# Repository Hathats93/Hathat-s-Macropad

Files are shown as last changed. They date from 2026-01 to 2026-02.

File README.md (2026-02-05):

# Hathats' Macropad

# Complete case with switches and keycaps installed
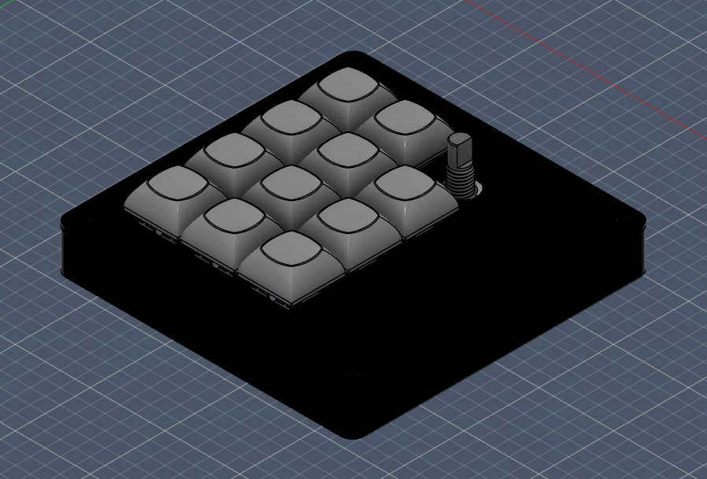
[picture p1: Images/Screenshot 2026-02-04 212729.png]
image alt


# Bare case (top and bottom)
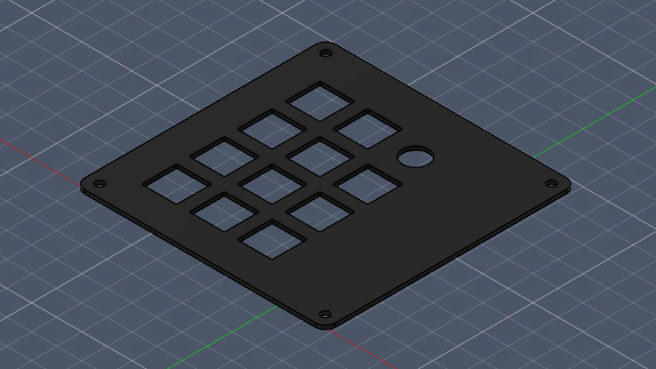
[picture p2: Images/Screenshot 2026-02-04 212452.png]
image alt


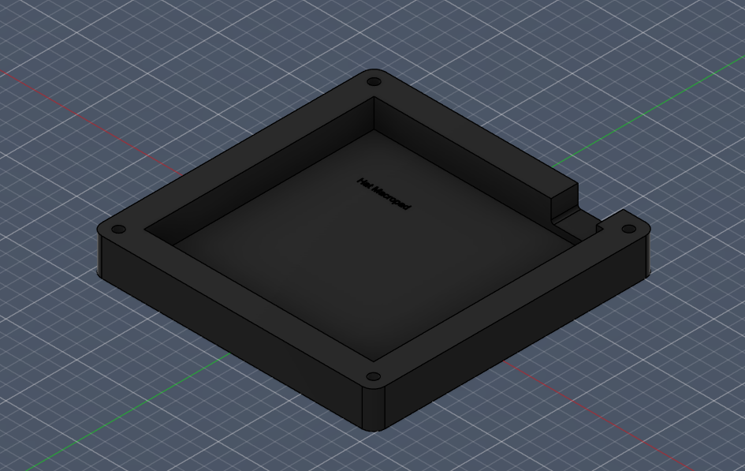
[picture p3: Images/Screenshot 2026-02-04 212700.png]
image alt


# PCB schematic
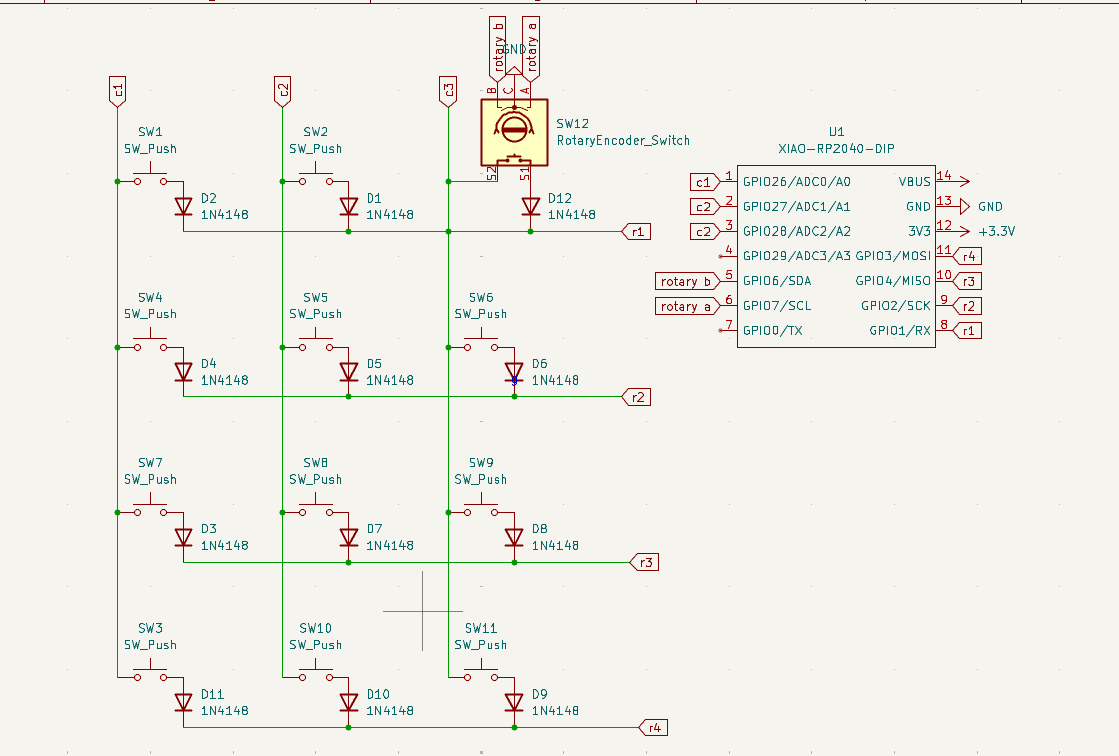
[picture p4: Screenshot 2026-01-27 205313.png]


# PCB layout
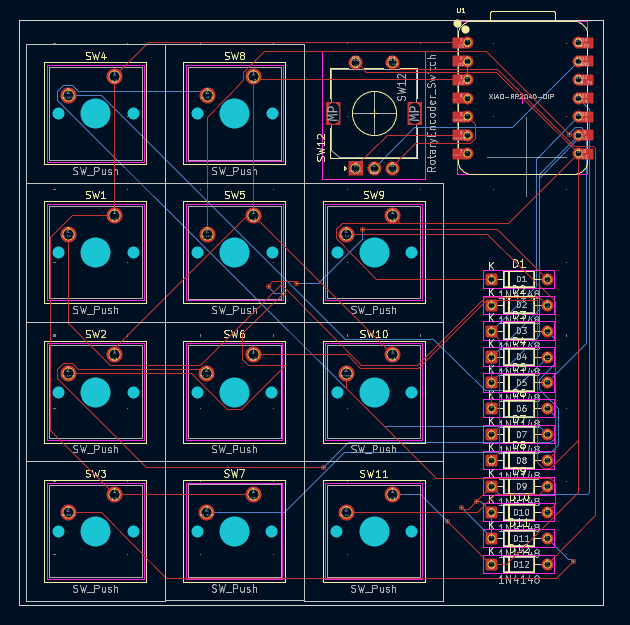
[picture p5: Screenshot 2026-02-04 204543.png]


##  Bill of Materials/BOM
List of all parts used in my hackpad:

| Part | Quantity | Description | 
|---|---|---|
| Mechanical Key Switches | 11 | MX-style switches |
| DSA Keycaps | 11 | Compatible with MX switches | 
| Seeed XIAO RP2040 | 1 | Microcontroller | 
| EC11 Rotary Encoder | 1 | Volume control | 
| PCB | 1 | Double-sided | 
| Case | 1 | 3D printed |

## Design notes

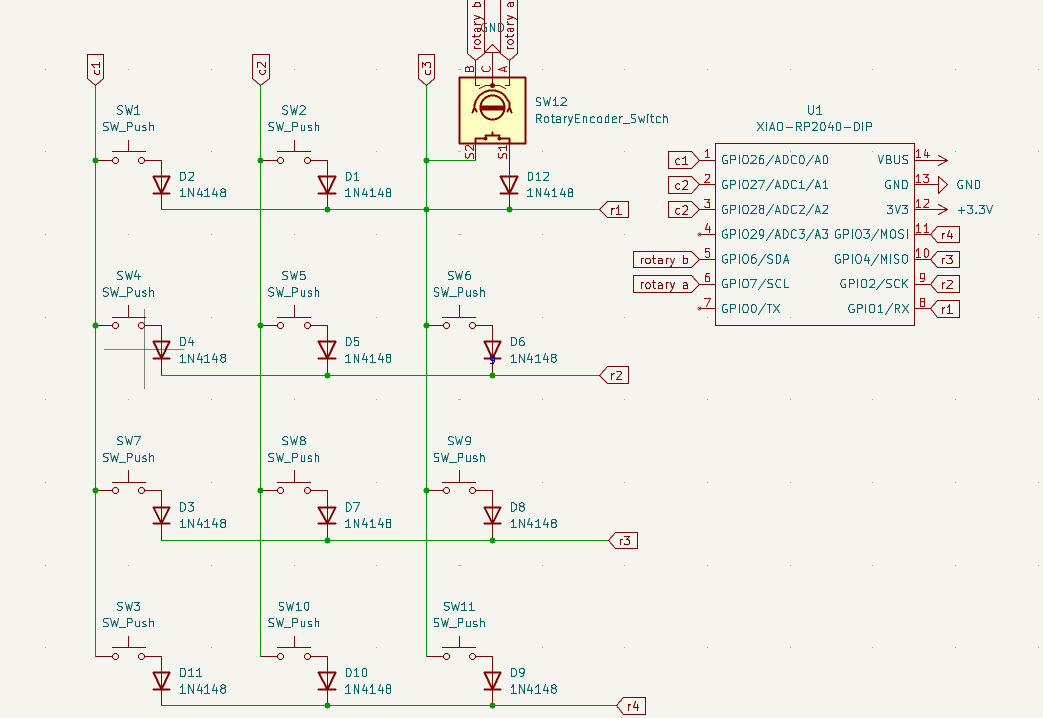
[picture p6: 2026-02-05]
Images/Screenshot 2026-01-21 171241.png

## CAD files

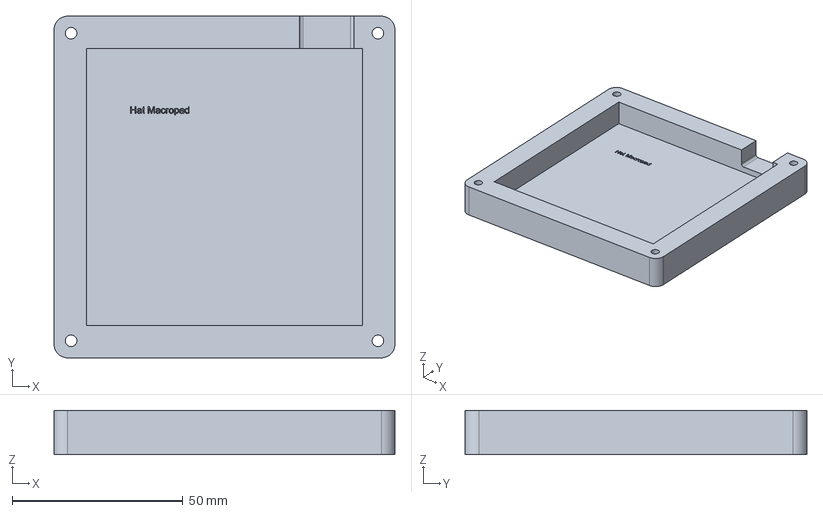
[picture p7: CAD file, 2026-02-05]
Production/case bottom.step
100.0 x 100.2 x 13.0 mm

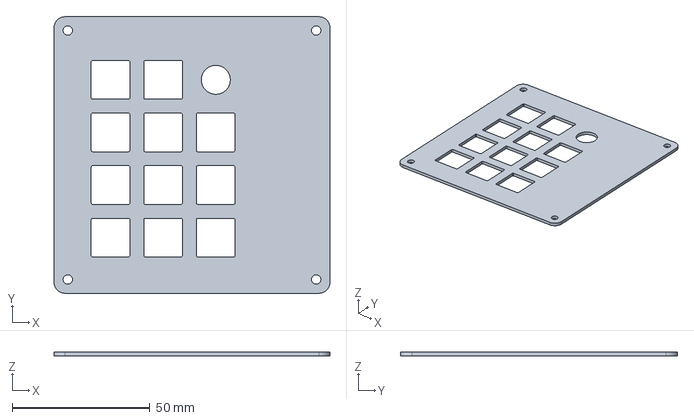
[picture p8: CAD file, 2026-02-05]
Production/case top.step
100.0 x 100.2 x 1.50 mm

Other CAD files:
CAD/case bottom.step
CAD/case top.step

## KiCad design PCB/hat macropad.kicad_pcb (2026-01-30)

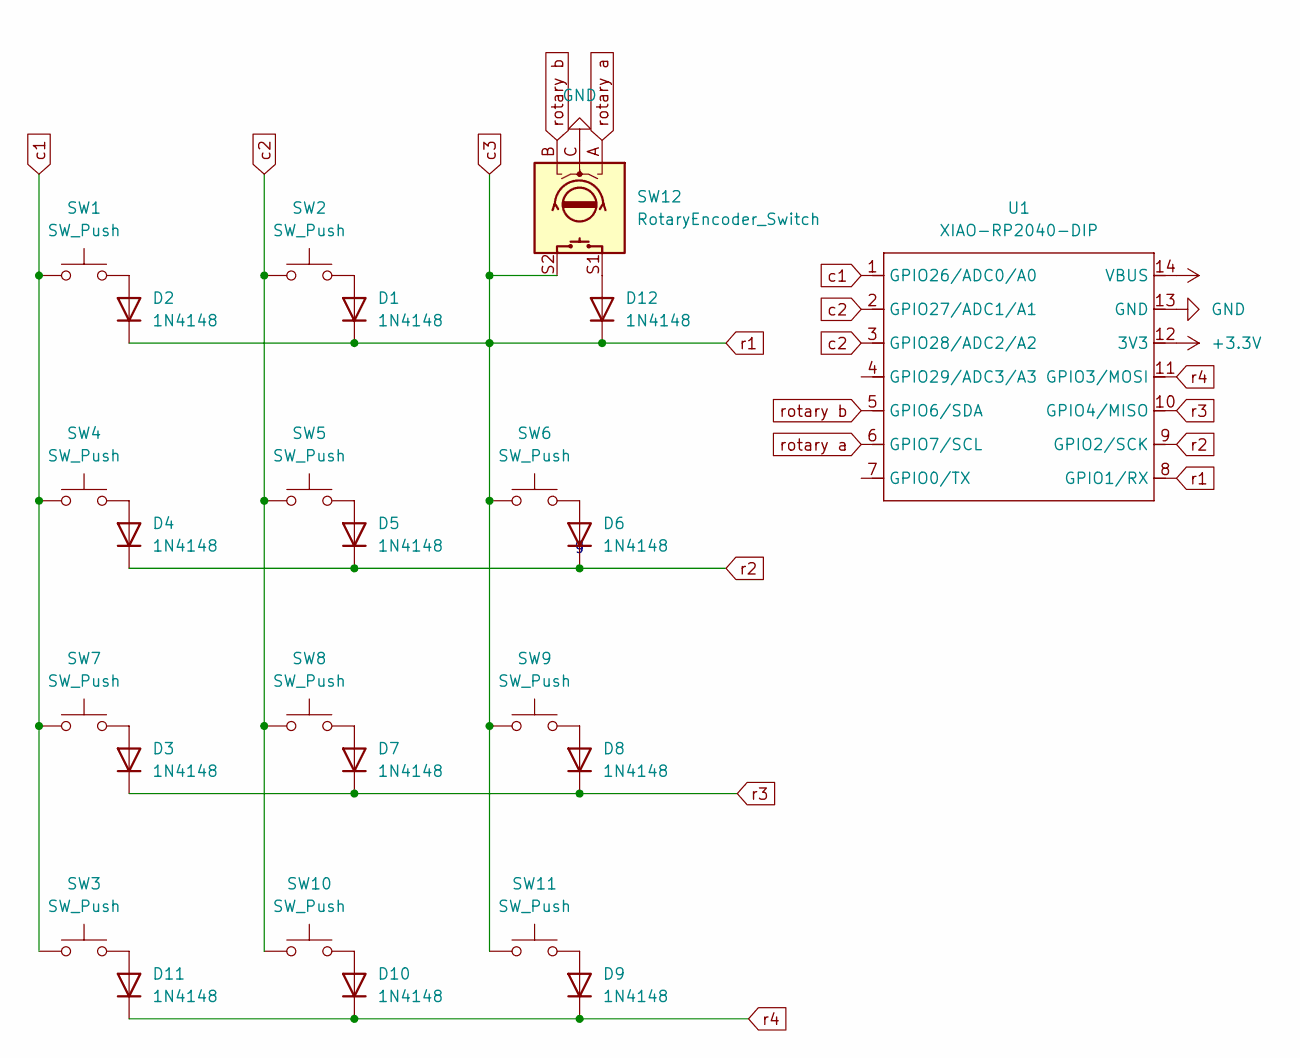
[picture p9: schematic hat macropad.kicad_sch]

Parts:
D1, D2, D3, D4, D5, D6, D7, D8, D9, D10, D11, D12: 1N4148; D_DO-35_SOD27_P7.62mm_Horizontal
SW1, SW2, SW3, SW4, SW5, SW6, SW7, SW8, SW9, SW10, SW11: SW_Push; SW_Cherry_MX_1.00u_PCB
SW12: RotaryEncoder_Switch; RotaryEncoder_Alps_EC11E-Switch_Vertical_H20mm
U1: XIAO-RP2040-DIP

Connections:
+3.3V: U1.12 (3V3)
+5V: U1.14 (VBUS)
GND: SW12.C, U1.13 (GND)
unnamed: D1.2 (A), SW2.2
unnamed: D2.2 (A), SW1.2
unnamed: D3.2 (A), SW7.2
unnamed: D4.2 (A), SW4.2
unnamed: D5.2 (A), SW5.2
unnamed: D6.2 (A), SW6.2
unnamed: D7.2 (A), SW8.2
unnamed: D8.2 (A), SW9.2
unnamed: D9.2 (A), SW11.2
unnamed: D10.2 (A), SW10.2
unnamed: D11.2 (A), SW3.2
unnamed: D12.2 (A), SW12.S1
c1: SW1.1, SW3.1, SW4.1, SW7.1, U1.1 (GPIO26/ADC0/A0)
c2: SW2.1, SW5.1, SW8.1, SW10.1, U1.2 (GPIO27/ADC1/A1), U1.3 (GPIO28/ADC2/A2)
c3: D1.1 (K), D2.1 (K), D12.1 (K), SW6.1, SW9.1, SW11.1, SW12.S2, U1.8 (GPIO1/RX)
r2: D4.1 (K), D5.1 (K), D6.1 (K), U1.9 (GPIO2/SCK)
r3: D3.1 (K), D7.1 (K), D8.1 (K), U1.10 (GPIO4/MISO)
r4: D9.1 (K), D10.1 (K), D11.1 (K), U1.11 (GPIO3/MOSI)
rotary a: SW12.A, U1.6 (GPIO7/SCL)
rotary b: SW12.B, U1.5 (GPIO6/SDA)

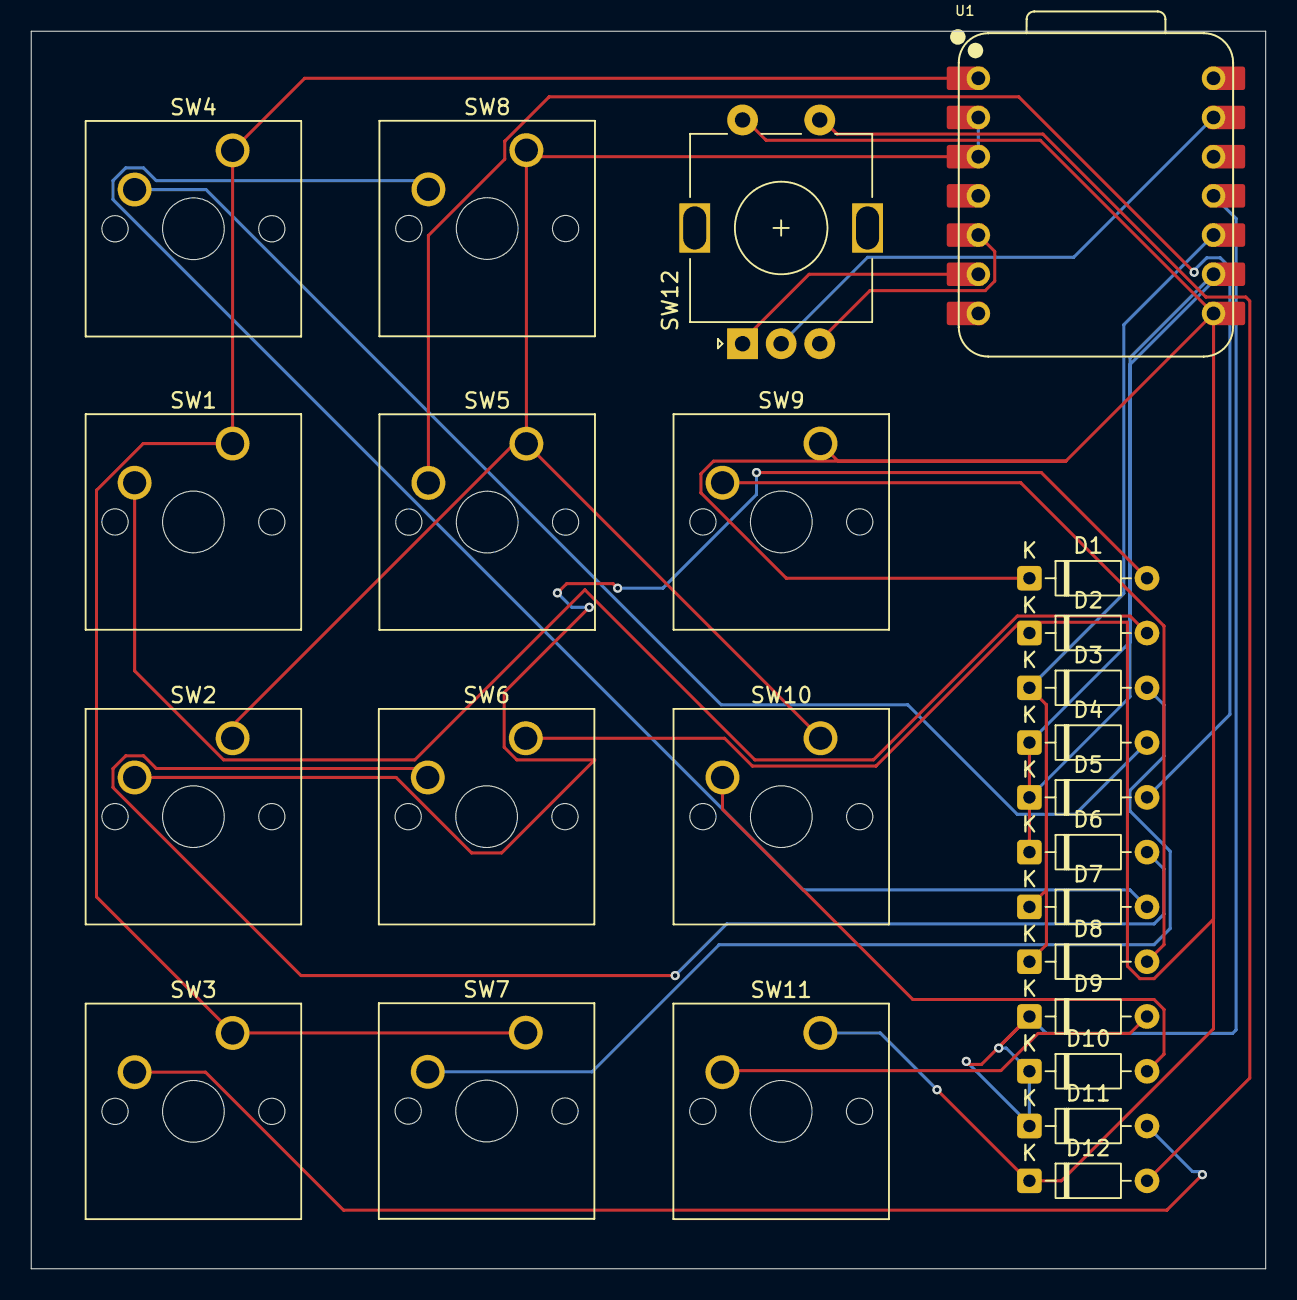
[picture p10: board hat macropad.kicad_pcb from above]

Board: 2 copper layers, 80.0 x 80.2 mm, 25 parts (0 on the bottom side), 21 nets.

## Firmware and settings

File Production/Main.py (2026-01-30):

import board
from kmk.kmk_keyboard import KMKKeyboard
from kmk.keys import KC
from kmk.handlers.sequences import send_string, simple_key_sequence
from kmk.modules.encoder import EncoderHandler
from kmk.layers import Layers

keyboard = KMKKeyboard()

# --------------------
# MATRIX (PCB MATCHED)
# --------------------
# Columns: c1=GP26, c2=GP27, c3=GP28
keyboard.col_pins = (board.GP26, board.GP27, board.GP28)

# Rows: r1=GP1, r2=GP2, r3=GP4, r4=GP3
keyboard.row_pins = (board.GP1, board.GP2, board.GP4, board.GP3)

keyboard.diode_orientation = keyboard.DIODE_COL2ROW

# --------------------
# MODULES
# --------------------
layers = Layers()
keyboard.modules.append(layers)

encoder = EncoderHandler()
keyboard.modules.append(encoder)

# Encoder pins: (A, B, None)
# Push button is wired into the matrix, not here
encoder.pins = ((board.GP7, board.GP6, None),)

# Encoder rotation: CCW = volume down, CW = volume up
encoder.map = [
    ((KC.VOLD, KC.VOLU),)
]

# --------------------
# CUSTOM MACROS (Windows)
# --------------------
def open_app(path):
    """Launch a Windows app or URL using Win + R."""
    return simple_key_sequence([
        KC.LGUI(KC.R),
        0.2,
        send_string(path + '\n'),
    ])

SCREENSHOT = KC.LGUI(KC.LSFT(KC.S))

MODRINTH = open_app("C:/Users/manuy/AppData/Local/Modrinth App/Modrinth App.exe")
AFTERBURNER = open_app("C:/Program Files (x86)/MSI Afterburner/MSIAfterburner.exe")
YTMUSIC = open_app("https://music.youtube.com/playlist?list=PLo6qklPTwjaYW88PUh1sFuyacack23Zj_")
YOUTUBE = open_app("https://www.youtube.com")
CHROME = open_app("C:/Program Files/Google/Chrome/Application/chrome.exe")

# Windows Action Center (Bluetooth, Wi-Fi, etc.)
BLUETOOTH = KC.LGUI(KC.A)

# --------------------
# KEYMAP (4 × 3, Single Layer)
# --------------------
keyboard.keymap = [
    [
        KC.MPRV,    KC.MNXT,    KC.MUTE,      # R1 (encoder push = MUTE)
        CHROME,     KC.COPY,    KC.PASTE,     # R2
        SCREENSHOT, MODRINTH,   AFTERBURNER,  # R3
        BLUETOOTH,  YOUTUBE,    YTMUSIC,      # R4
    ]
]

# --------------------
# START KEYBOARD
# --------------------
if __name__ == "__main__":
    keyboard.go()

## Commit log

2026-01-30 Added PCB code files
    Added pcb files from kikad
    [hat macropad.kicad_pcb, hat macropad.kicad_sch]
2026-02-04 Added optimized case step file
    changed case file
    [Main Case.step]
2026-02-04 removed file
    removed file
    [hat macropad.kicad_sch]
2026-02-05 added case step with all components
2026-02-05 deleted old case step file
    [Main Case.step]
2026-02-05 added bare case
    [Black case bare.step]
2026-02-05 Added files to production folder
    added files to Production folder
    [case bottom.step, case top.step]
